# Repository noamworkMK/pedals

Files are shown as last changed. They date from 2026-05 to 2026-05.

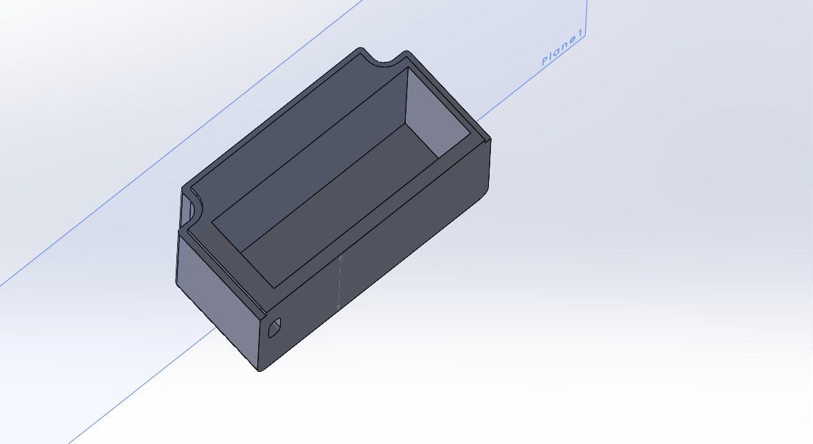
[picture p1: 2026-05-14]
Screenshot 2026-05-15 005842.jpg

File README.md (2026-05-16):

 Pitch Shifter:

System Overview
A frequency-tracking pitch shifter  The design avoids digital DSP in favor of a CD4046 Phase-Locked Loop (PLL) and CD4017 decade counter 
for interval sequencing.

im very connected to music and rock culture, and its all started when i talked with my friend about how expansive effect pedal are. and then i thought, maybe i can build one, so from there i searched for like a month on how to buld them, about the electronics of the audio, and the logic. and i asked myself how can i make it. and then i found kicad as almost the only free softwere that worked for me, and i learned how to use it, this project has alot of versions some of them are really bad, but thats how i learned to design a pcb.

the pcb design: 
this pcb design had a lot of changes, at first i had a 2 layers board, unorgenised and to big to be in the enclouser, and then i made it smaller, changed some foorpeint, rerouthed the pcb, added fillings, and i almost sent it for prodaction like that. and then i felt that something is misssing, and that i wanted to create a intresting pedal that will be good and easy, so in this version i addad relay switch to create a bypass and added caps and, more diods, and resistors to protect the parts from overload, backcurent, and stuff that willl ruin the board. and i changed the board size and redone the traces again to finaly fit my expactation and the enclouser. 


Screenshot 2026-05-15 005828 png
pcb

the leyers of the pcb: 
L-GREEN
L-BLUE
L-RED
L-ORANGE

the circuit: 
The circuit takes an audio, signal shifts its pitch down and outputs it with 5 selectable pitch steps controlled by a push button. The core chips are a CD4046 (handles the pitch shifting) and a CD4017 counter (steps through the 5 settings). A TL072 op-amp buffers the input signal, and five NSL-32 optocouplers that i swiched to VTL5C4 in prodaction becouse of avilablity. this optocouplers (optical) do the switching between pitch steps without noise, becouse there is not current passing between them.

scheamatic

logic schematics:

LOGIC SCH

audio schematics:

audio SCH

the battery compartment: 
i sd designed a 9v battary compartment in solidworks that will fit exactly in the enclouser


assembly:
i also created a 3d assambly of the pedal in solidworks, the assembly is partial becouse it would take me a lot of time to do every thing and its mainly for fitting and concepts. but the main parts are in there.

assmbly 5
assm2
essembly pitch

Technical Specifications:

Frequency Synthesis: CD4046 PLL tracks input frequency; CD4017 logic handles interval division/multiplication.
Analog Interface: VTL5C4 Vactrols integrated for smooth interval transitions.
Calibration: 5x 50k  trimmers for precise frequency offset tuning.
Input Stage: TL072 op-amp buffer for high-impedance guitar signal integrity.
Bypass: Relay-based switching system for transparent operation.



essembly pitch

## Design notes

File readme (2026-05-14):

 Pitch Shifter:

System Overview
A frequency-tracking pitch shifter utilizing a CMOS-based architecture. The design avoids digital DSP in favor of a CD4046 Phase-Locked Loop (PLL) and CD4017 decade counter 
for interval sequencing.

Technical Specifications:

Frequency Synthesis: CD4046 PLL tracks input frequency; CD4017 logic handles interval division/multiplication.
Analog Interface: NSL-32 Vactrols integrated for smooth interval transitions.
Calibration: 5x 50k on-board trimmers for precise frequency offset tuning.
Input Stage: TL072 op-amp buffer for high-impedance guitar signal integrity.
Bypass: Relay-based switching system for transparent operation.

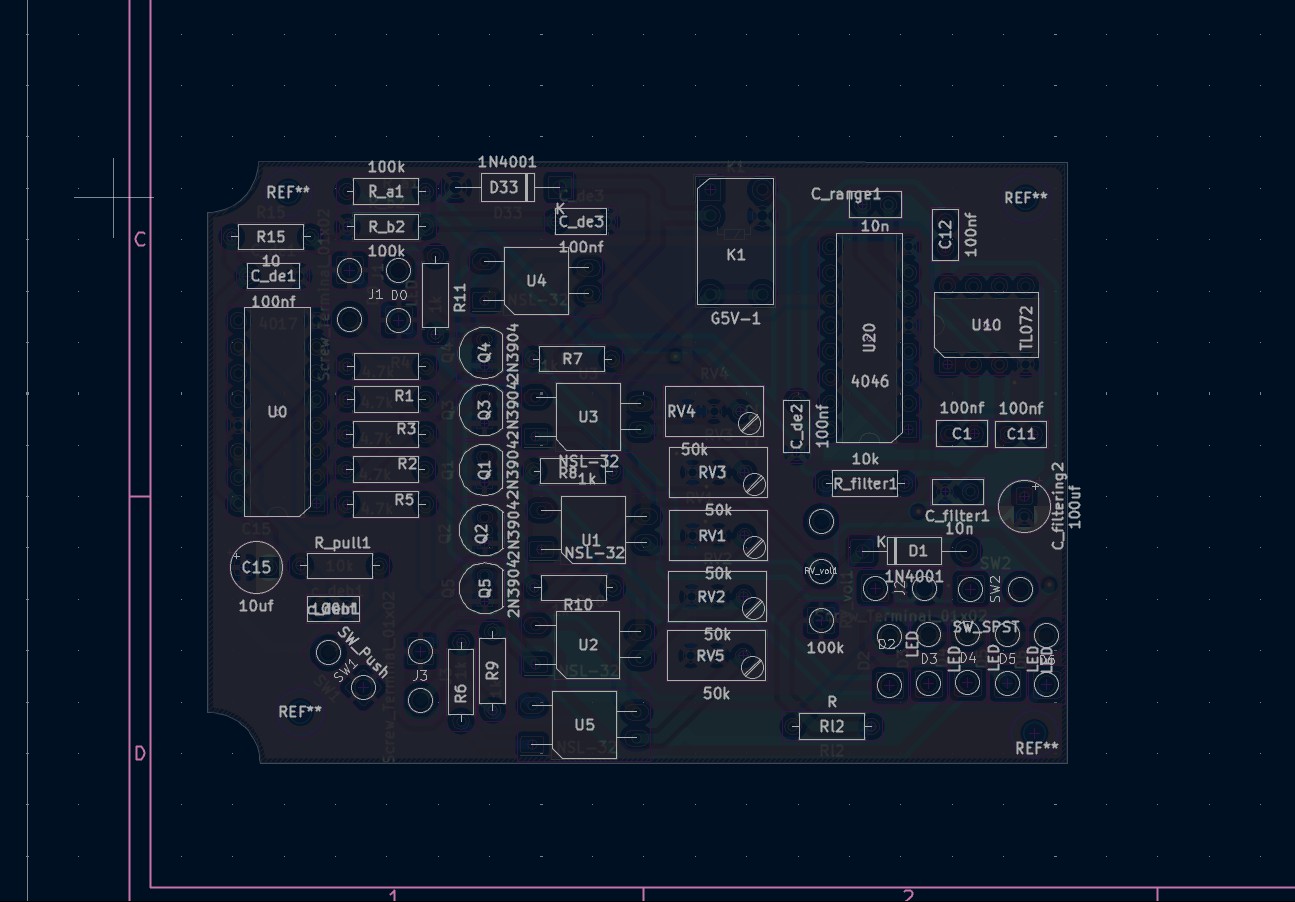
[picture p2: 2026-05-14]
Screenshot 2026-05-15 005828.png.jpg

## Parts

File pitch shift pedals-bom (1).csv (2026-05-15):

Name | Purpose | Quantity | Total Cost (USD) | Link | Distributor
Resistor 4k7 |  | 15 | 0.64 | https://he.aliexpress.com/item/1005011886443911.html
Resistor 1k |  | 18 | 0.64 | https://he.aliexpress.com/item/1005011886443911.html
Resistor 10R |  | 3 | 0.64 | https://he.aliexpress.com/item/1005011886443911.html
Resistor 100k |  | 6 | 0.64 | https://he.aliexpress.com/item/1005011886443911.html
Resistor 10k |  | 6 | 0.64 | https://he.aliexpress.com/item/1005011886443911.html
CD4046BE (PLL) |  | 3 | 1.38 | https://he.aliexpress.com/item/1005009254095244.html
CD4017BE (Counter) |  | 3 | 0.96 | https://he.aliexpress.com/item/1005009254095244.html
TL072CP (Op-Amp) |  | 3 | 0.74 | https://he.aliexpress.com/item/1005005109343906.html
VTL5C4 Vactrol |  | 15 | 6.93 | https://he.aliexpress.com/item/1005012095983599.html
SRD-09VDC Relay |  | 3 | 3.61 | https://he.aliexpress.com/item/1005008661364221.html
2N3904 Transistor |  | 15 | 2.27 | https://he.aliexpress.com/item/1005010396511377.html
1N4001 Diode |  | 6 | 1.53 | https://he.aliexpress.com/item/1005001552094086.html
50k Trimmer (3296W) |  | 15 | 2.20 | https://he.aliexpress.com/item/1005002304707308.html
100k Potentiometer |  | 3 | 0.66 | https://he.aliexpress.com/item/1005010651217191.html
3-PIN Toggle Switch |  | 3 | 8.33 | https://he.aliexpress.com/item/1005008914707882.html
125B Enclosure |  | 3 | 22.80
1/4" Mono Jacks |  | 6 | 8.67 | https://he.aliexpress.com/item/1005007527123760.html
Momentary Foot Switch |  | 3 | 20.03
LED + Holder Kit |  | 18 | 8.59 | https://he.aliexpress.com/item/1005003385738351.html
Capacitors (10n, 100n) |  | 13 | 3.20 | https://he.aliexpress.com/item/1005011747293156.html
Capacitors (10u, 100u) |  | 8 | 3.30 | https://he.aliexpress.com/item/1005006192445408.html

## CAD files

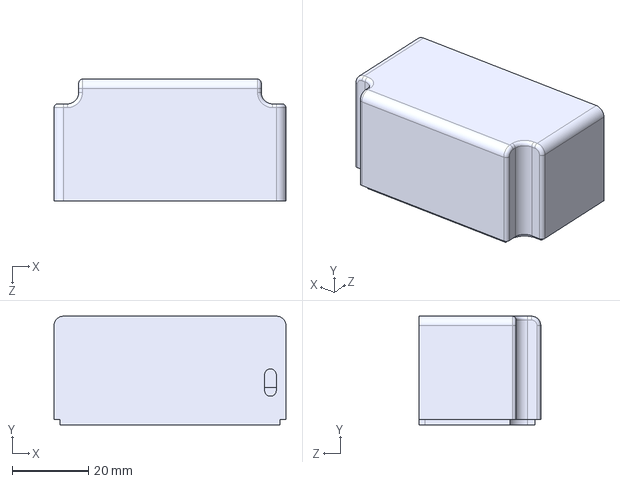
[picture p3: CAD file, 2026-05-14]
battary comp pitch - Copy.STEP
61.0 x 28.6 x 32.0 mm

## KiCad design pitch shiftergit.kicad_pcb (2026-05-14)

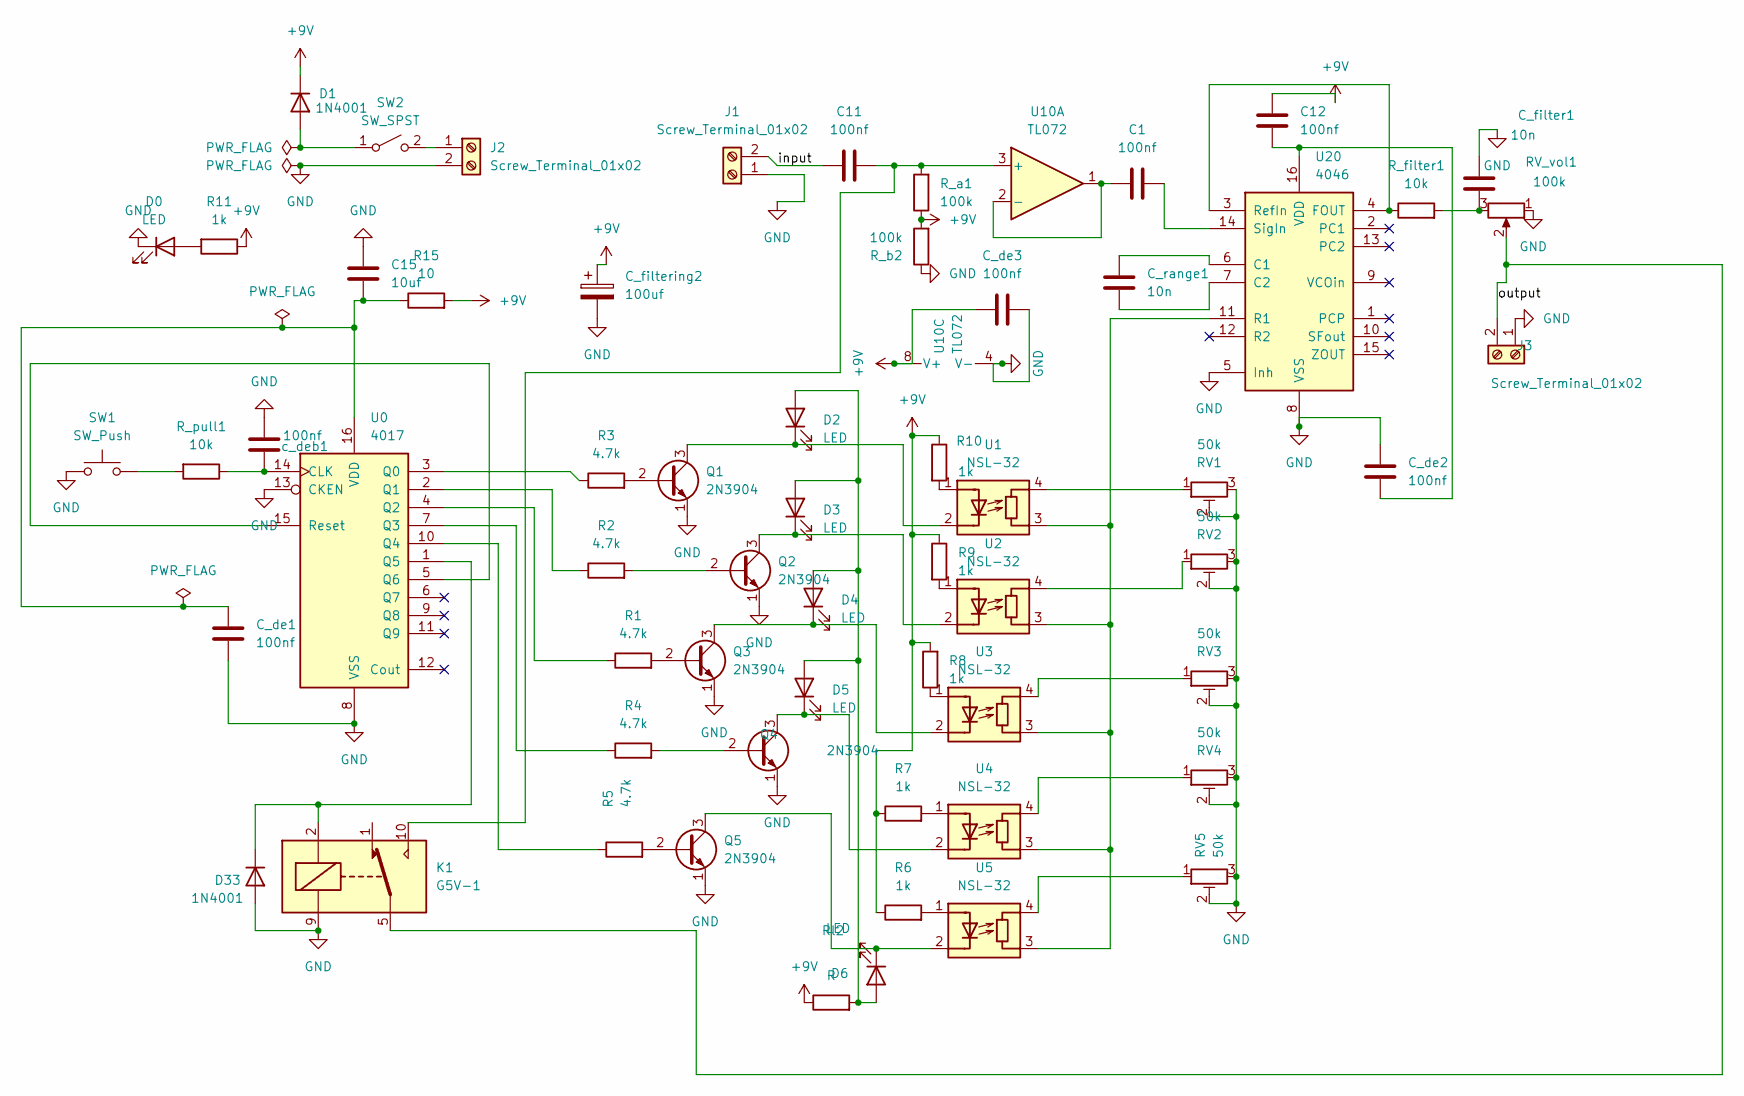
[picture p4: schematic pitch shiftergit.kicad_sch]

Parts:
C1, C11, C12: 100nf; C_Disc_D5.0mm_W2.5mm_P2.50mm
C15: 10uf; CP_Radial_D5.0mm_P2.50mm
C_de1, C_de2, C_de3: 100nf; C_Disc_D5.0mm_W2.5mm_P5.00mm
C_filter1: 10n; C_Disc_D5.0mm_W2.5mm_P2.50mm
C_filtering2: 100uf; CP_Radial_D5.0mm_P2.00mm
C_range1: 10n; C_Disc_D5.0mm_W2.5mm_P2.50mm
D0, D2, D3, D4, D5, D6: LED; SolderWire-0.75sqmm_1x02_P4.8mm_D1.25mm_OD2.3mm
D1, D33: 1N4001; D_DO-41_SOD81_P10.16mm_Horizontal
J1, J2, J3: Screw_Terminal_01x02; SolderWire-0.75sqmm_1x02_P4.8mm_D1.25mm_OD2.3mm
K1: G5V-1; Relay_SPDT_Omron_G5V-1
Q1, Q2, Q3, Q4, Q5: 2N3904; TO-92_Inline
R1, R2, R3, R4, R5: 4.7k; R_Axial_DIN0207_L6.3mm_D2.5mm_P7.62mm_Horizontal
R6, R7, R8, R9, R10, R11: 1k; R_Axial_DIN0207_L6.3mm_D2.5mm_P7.62mm_Horizontal
R15: 10; R_Axial_DIN0207_L6.3mm_D2.5mm_P7.62mm_Horizontal
RV1, RV2, RV3, RV4, RV5: 50k; Potentiometer_Bourns_3296W_Vertical
RV_vol1: 100k; SolderWire-0.75sqmm_1x03_P4.8mm_D1.25mm_OD2.3mm
R_a1: 100k; R_Axial_DIN0207_L6.3mm_D2.5mm_P7.62mm_Horizontal
R_b2: 100k; R_Axial_DIN0207_L6.3mm_D2.5mm_P7.62mm_Horizontal
R_filter1: 10k; R_Axial_DIN0207_L6.3mm_D2.5mm_P7.62mm_Horizontal
R_pull1: 10k; R_Axial_DIN0207_L6.3mm_D2.5mm_P7.62mm_Horizontal
Rl2: R; R_Axial_DIN0207_L6.3mm_D2.5mm_P7.62mm_Horizontal
SW1: SW_Push; SolderWire-0.75sqmm_1x02_P4.8mm_D1.25mm_OD2.3mm
SW2: SW_SPST; SolderWire-0.75sqmm_1x02_P4.8mm_D1.25mm_OD2.3mm
U0: 4017; DIP-16_W7.62mm
U1, U2, U3, U4, U5: NSL-32; Luna_NSL-32
U10: TL072; DIP-8_W7.62mm
U20: 4046; DIP-16_W7.62mm
c_deb1: 100nf; C_Disc_D5.0mm_W2.5mm_P2.50mm

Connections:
+9V: C12.1, C_de3.1, C_filtering2.1, D1.1 (K), R6.1, R7.1, R8.2, R9.1, R10.1, R11.1, R15.2, R_a1.1, R_b2.2, Rl2.1, U10.8 (V+)
/input: C11.1, J1.2
/output: J3.2, K1.5, K1.6, RV_vol1.2
GND: C15.1, C_de1.2, C_de2.1, C_de3.2, C_filter1.1, C_filtering2.2, D0.1 (K), D33.2 (A), J1.1, J2.2, J3.1, K1.9, Q1.1 (E), Q2.1 (E), Q3.1 (E), Q4.1 (E), Q5.1 (E), RV1.2, RV1.3, RV2.2, RV2.3, RV3.2, RV3.3, RV4.2, RV4.3, RV5.2, RV5.3, RV_vol1.1, R_b2.1, SW1.1, U0.8 (VSS), U0.13 (CKEN), U10.4 (V-), U20.5 (Inh), U20.8 (VSS), c_deb1.1
unnamed: C_filter1.2, RV_vol1.3, R_filter1.2
unnamed: D0.2 (A), R11.2
unnamed: D1.2 (A), SW2.1 (A)
unnamed: D2.2 (A), D3.2 (A), D4.2 (A), D5.2 (A), D6.2 (A), Rl2.2
unnamed: D2.1 (K), Q1.3 (C), U1.2 (K)
unnamed: D3.1 (K), Q2.3 (C), U2.2 (K)
unnamed: D4.1 (K), Q3.3 (C), U3.2 (K)
unnamed: D5.1 (K), Q4.3 (C), U4.2 (K)
unnamed: D6.1 (K), Q5.3 (C), U5.2 (K)
unnamed: D33.1 (K), K1.2, U0.1 (Q5)
unnamed: J2.1, SW2.2 (B)
unnamed: Q1.2 (B), R3.2
unnamed: Q2.2 (B), R2.2
unnamed: Q3.2 (B), R1.2
unnamed: Q4.2 (B), R4.2
unnamed: Q5.2 (B), R5.2
unnamed: RV1.1, U1.4 (R)
unnamed: RV2.1, U2.4 (R)
unnamed: RV3.1, U3.4 (R)
unnamed: RV4.1, U4.4 (R)
unnamed: RV5.1, U5.4 (R)
unnamed: R_pull1.2, SW1.2
unnamed: R_pull1.1, U0.14 (CLK), c_deb1.2
unnamed: R3.1, U0.3 (Q0)
unnamed: R2.1, U0.2 (Q1)
unnamed: R1.1, U0.4 (Q2)
unnamed: R4.1, U0.7 (Q3)
unnamed: R5.1, U0.10 (Q4)
unnamed: U0.5 (Q6), U0.15 (Reset)
unnamed: C15.2, C_de1.1, R15.1, U0.16 (VDD)
unnamed: R10.2, U1.1 (A)
unnamed: R9.2, U2.1 (A)
unnamed: R8.1, U3.1 (A)
unnamed: R7.2, U4.1 (A)
unnamed: R6.2, U5.1 (A)
unnamed: C11.2, K1.10, R_a1.2, U10.3 (+)
unnamed: C1.1, U10.1, U10.2 (-)
unnamed: C_range1.1, U20.6 (C1)
unnamed: C_range1.2, U20.7 (C2)
unnamed: R_filter1.1, U20.3 (RefIn), U20.4 (FOUT)
unnamed: U1.3 (R), U2.3 (R), U3.3 (R), U4.3 (R), U5.3 (R), U20.11 (R1)
unnamed: C1.2, U20.14 (SigIn)
unnamed: C12.2, C_de2.2, U20.16 (VDD)

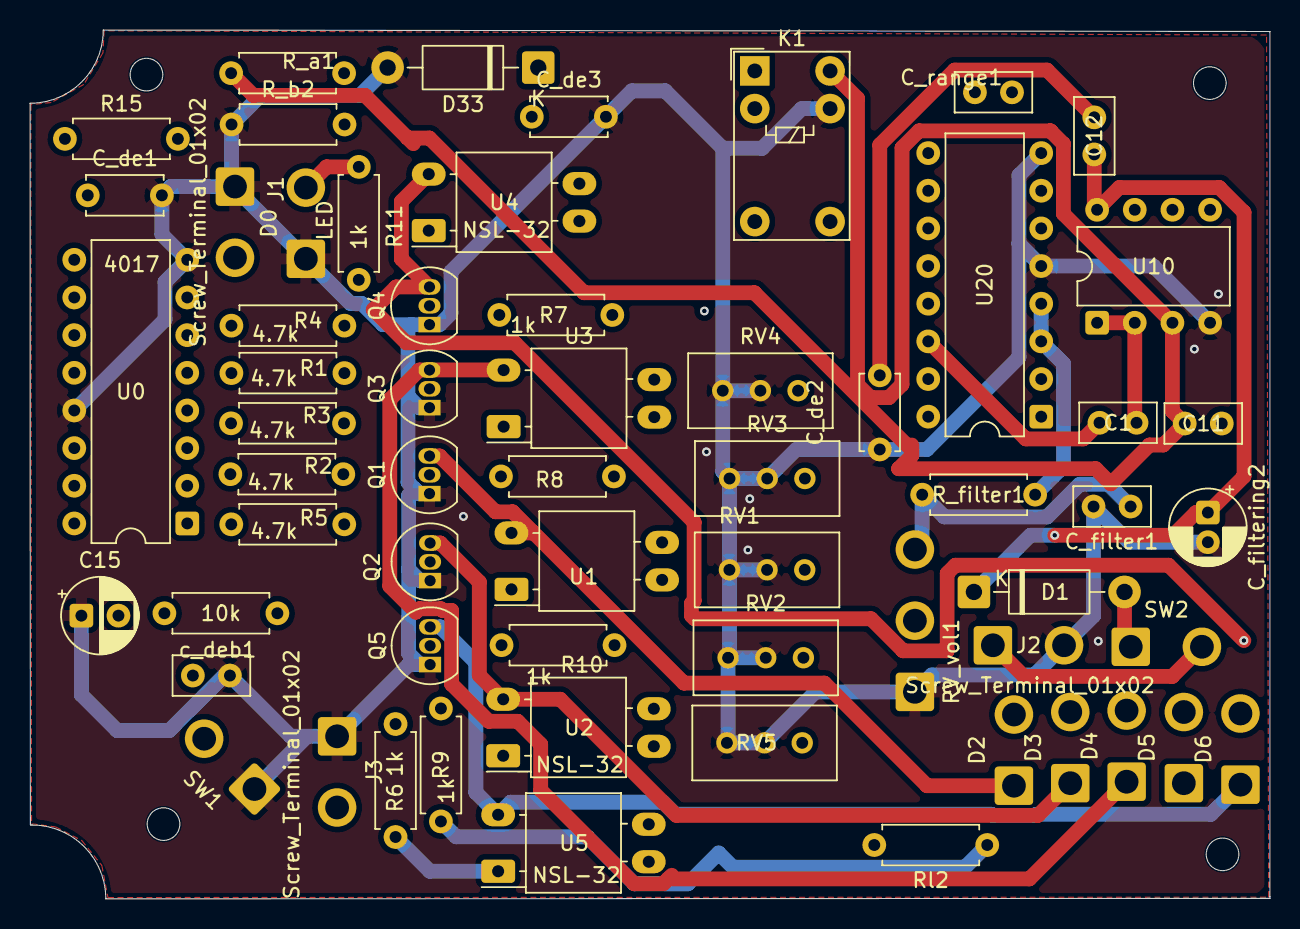
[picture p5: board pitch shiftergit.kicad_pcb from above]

Board: 4 copper layers, 83.6 x 58.6 mm, 61 parts (0 on the bottom side), 47 nets.

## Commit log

2026-05-14 Add project overview and technical specifications to README
    Added a detailed overview and specifications for the pitch shifter project.
2026-05-16 Enhance README with project details and images
    Expanded the README with personal background, PCB design evolution, circuit details, and assembly information for the pitch shifter project.
